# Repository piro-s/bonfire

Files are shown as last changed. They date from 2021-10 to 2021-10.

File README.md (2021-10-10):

# bonfire
Modernization of the night light bought on Ali in the form of a bonfire from Dark Souls.
The original uses three 5050 RGB LEDs with IR remote control. The range of this control is +- 50 centimeters, you can choose several glow colors. I created a new board to replace the one that was there, without control, just a glow in the form of a fluttering flame (it seems to work). The blue color of the diodes is not used, the red one works constantly, and green, with a PWM, turns out to be flickering yellow, creating the effect of a flame. Everything is controlled by one 48 mega, 6 PWM channels, each controls its own transistor, each has 8 LEDs.

Board size: circle, diameter 98 mm.
v0.1:
1. no remote control (why? It's a fire);
2. instead of 3 LEDs, now 48;
3. work from an external 5V source;
4. consumption about 350mA.

***
## scheme:
### scheme_v0.1:
[pdf](docs/scheme_v0.1.pdf)

***
## pcb:
#### top assambled:
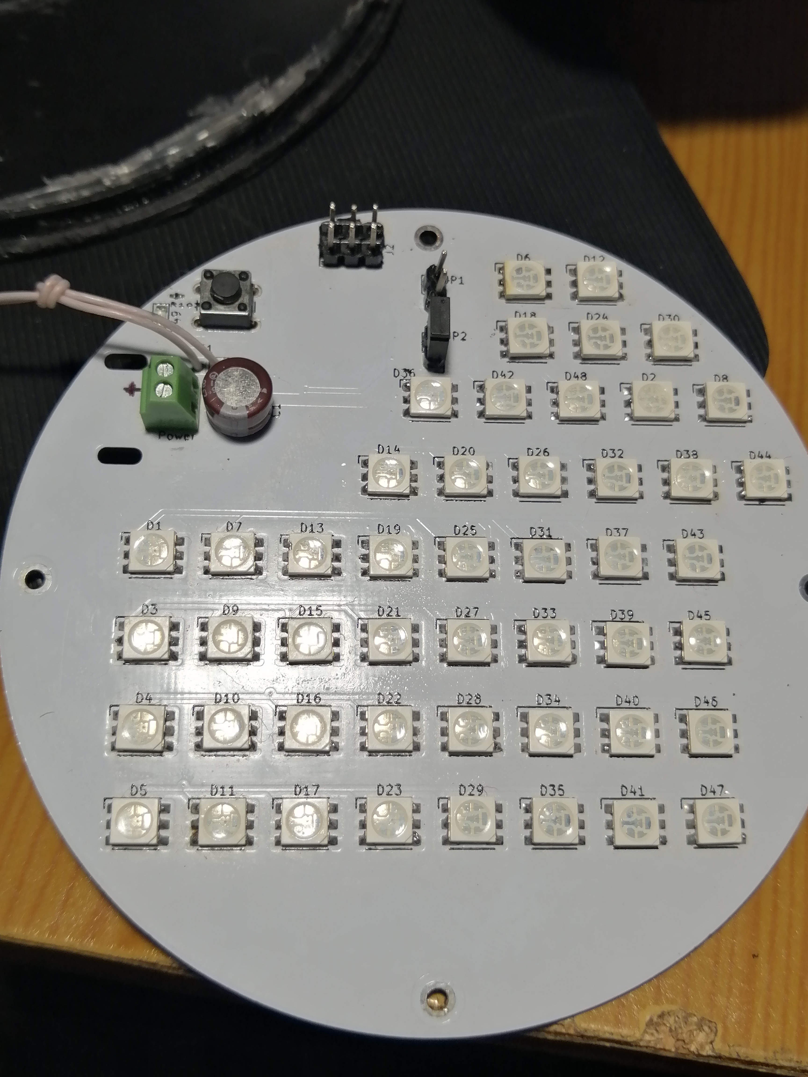
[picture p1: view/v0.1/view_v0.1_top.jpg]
top_assambled


***
## bonfire:
#### assambled:
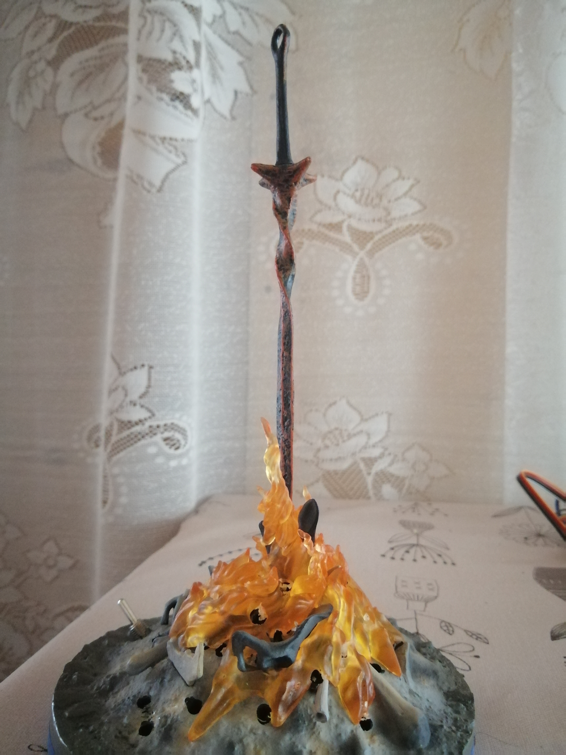
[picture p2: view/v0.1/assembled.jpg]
assambled

#### work:
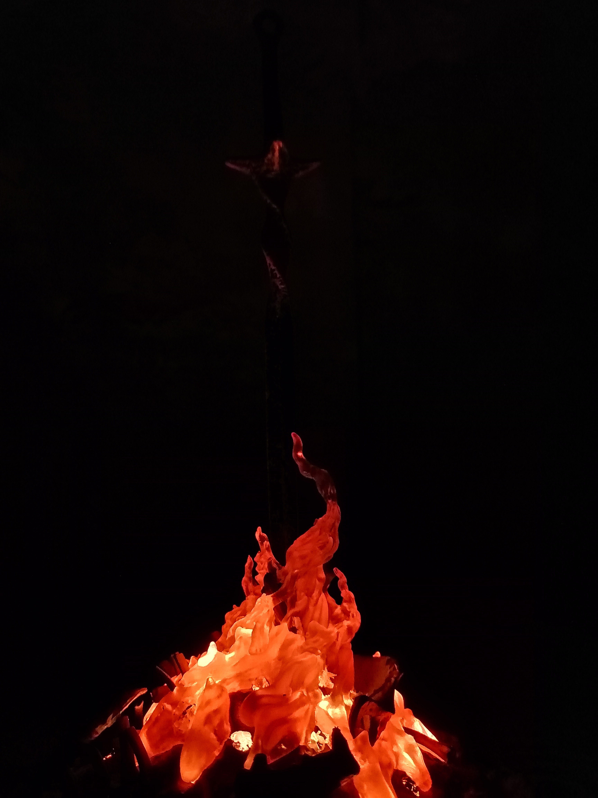
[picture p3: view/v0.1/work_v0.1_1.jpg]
work_1

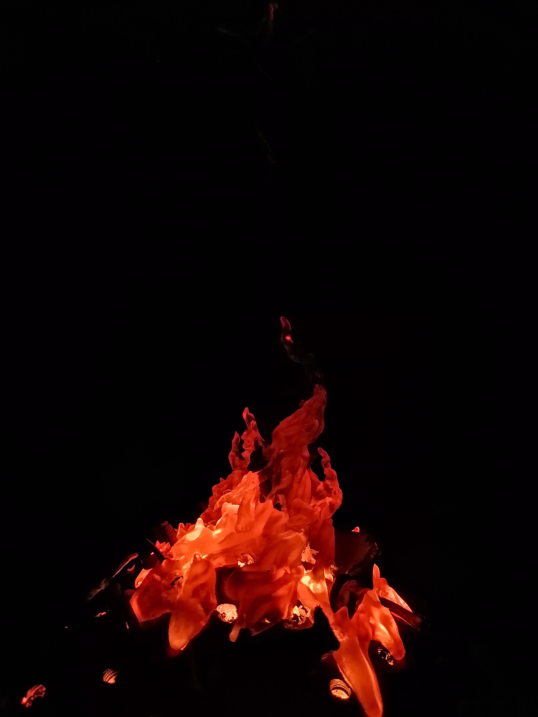
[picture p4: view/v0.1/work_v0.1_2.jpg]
work_2

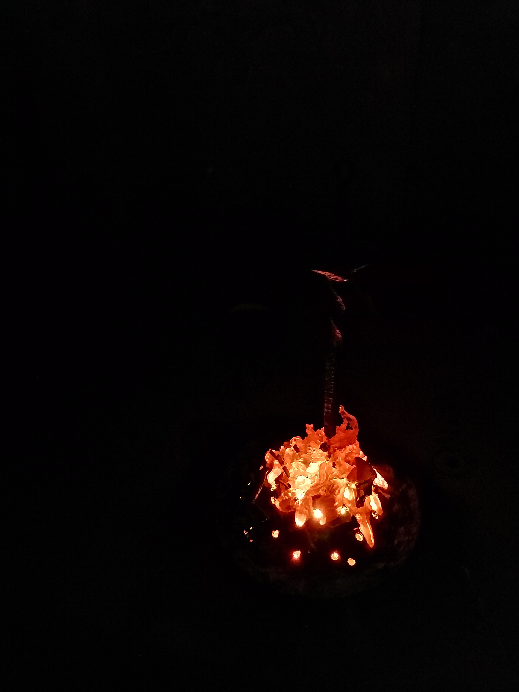
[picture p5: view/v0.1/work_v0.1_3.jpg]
work_3


***
## gerber:
Archive for production:
[gerber_v0.1](https://github.com/piro-s/bonfire/raw/master/gerber/bonfire_v0.1.zip)

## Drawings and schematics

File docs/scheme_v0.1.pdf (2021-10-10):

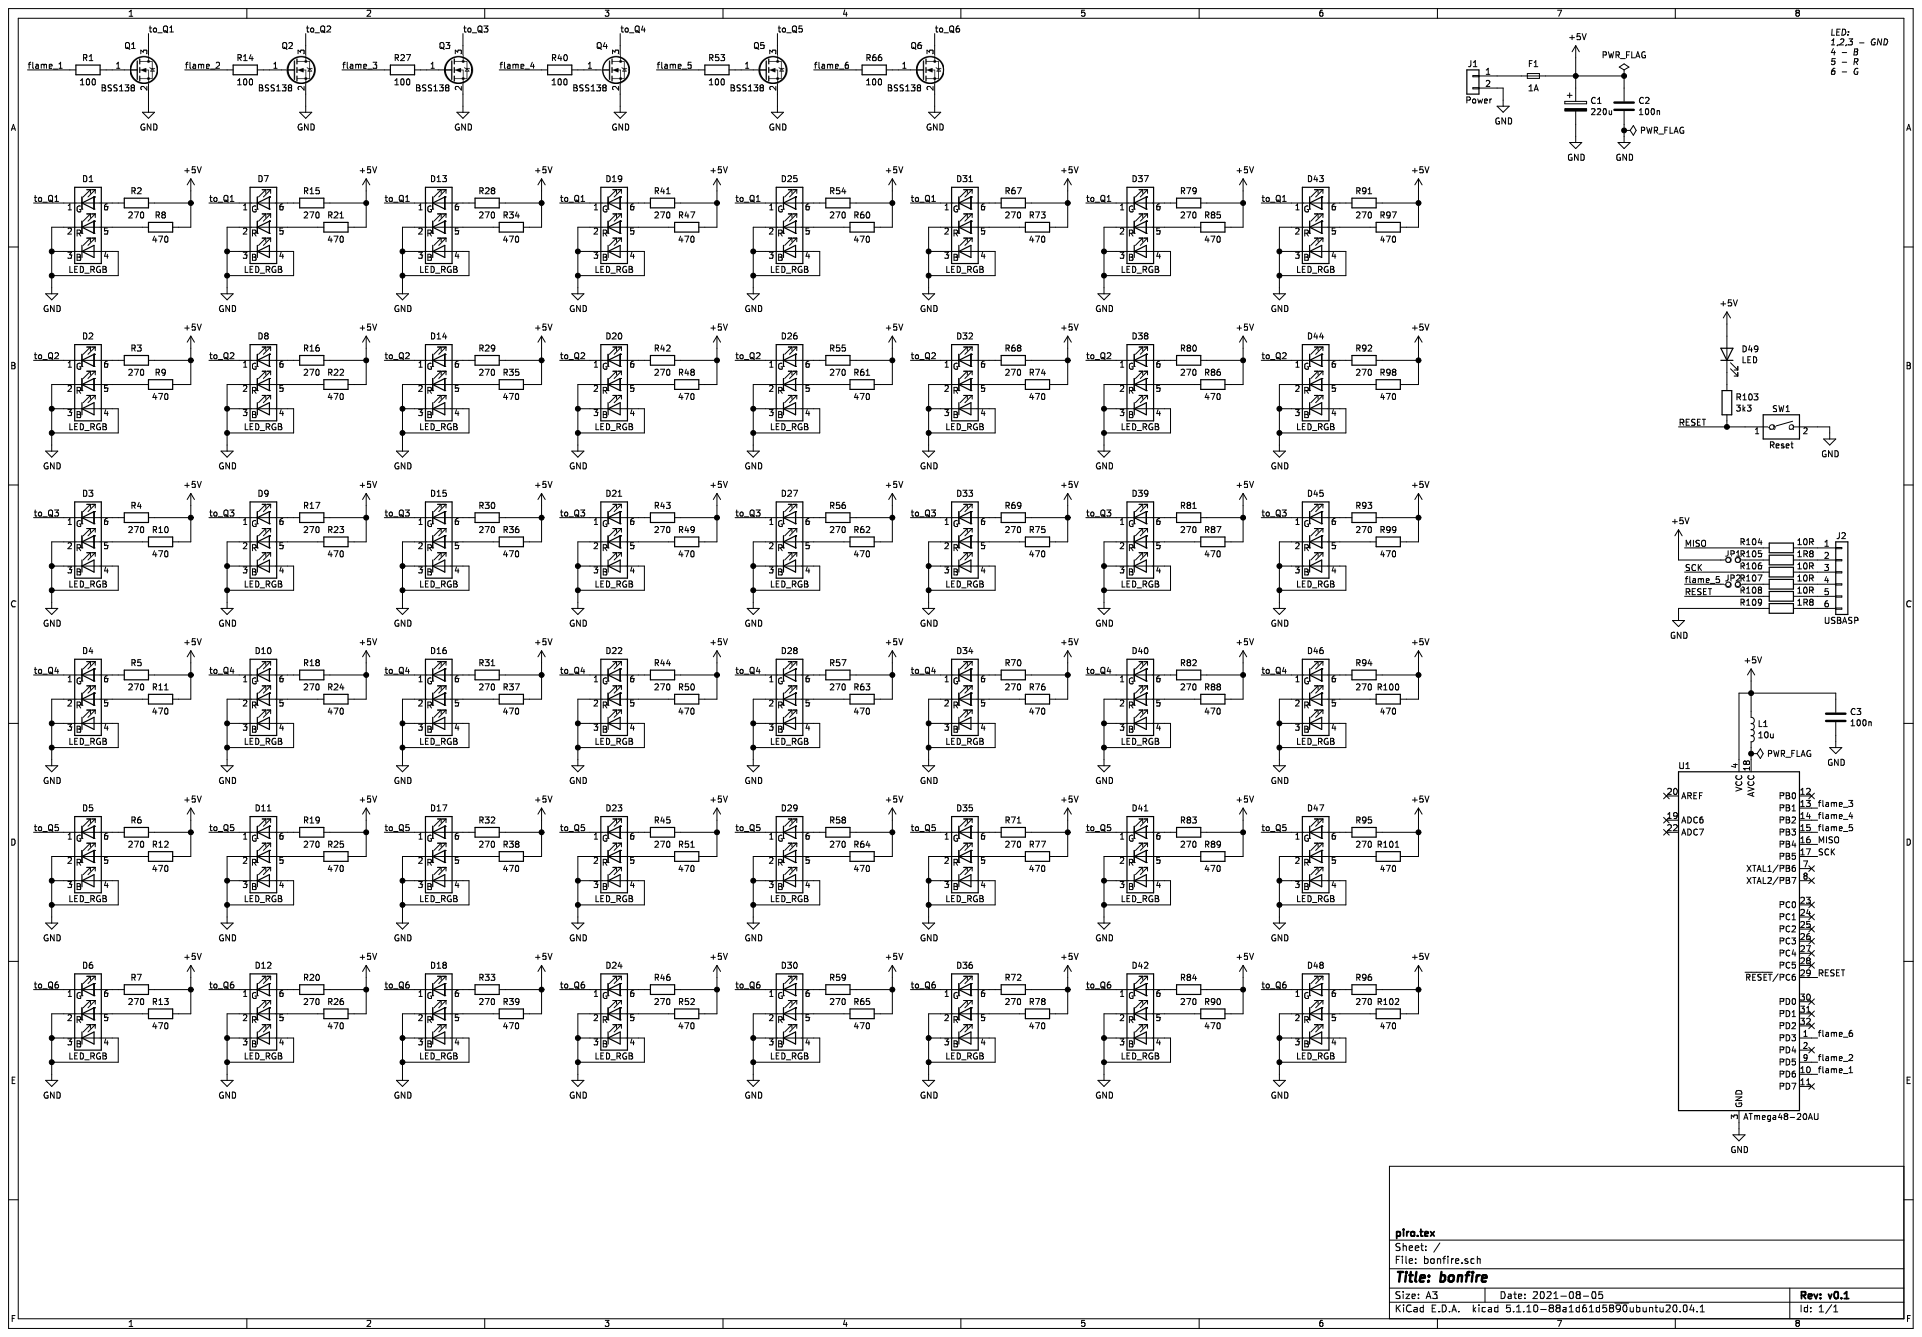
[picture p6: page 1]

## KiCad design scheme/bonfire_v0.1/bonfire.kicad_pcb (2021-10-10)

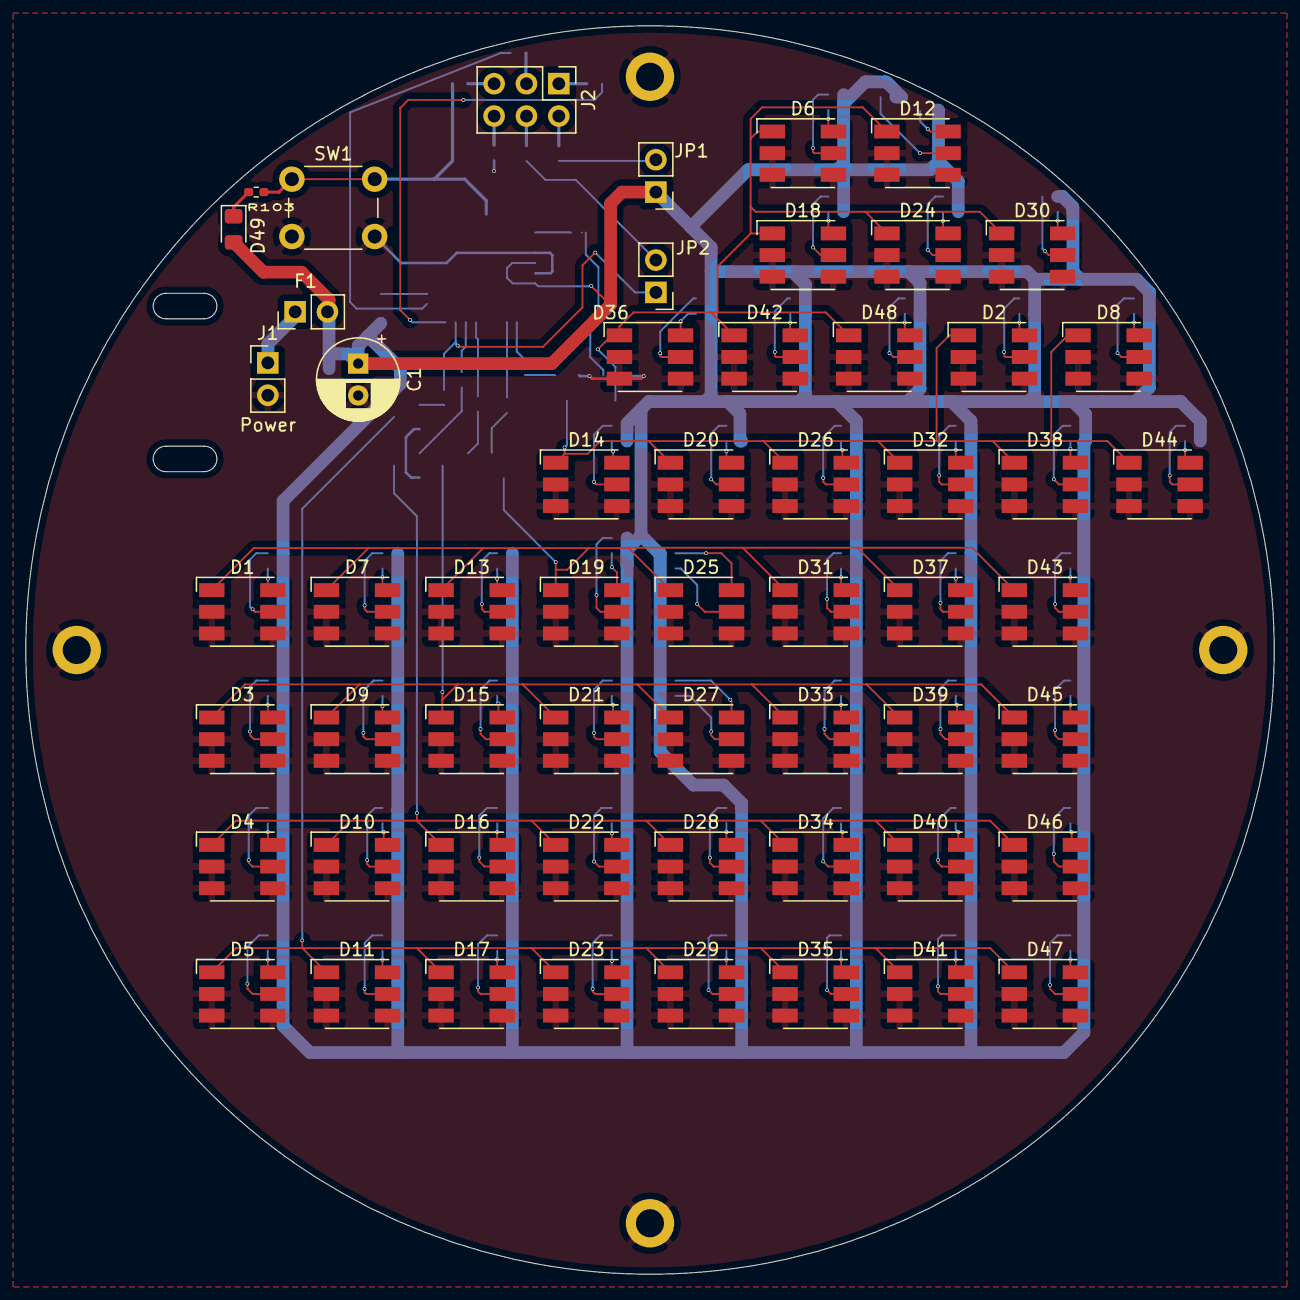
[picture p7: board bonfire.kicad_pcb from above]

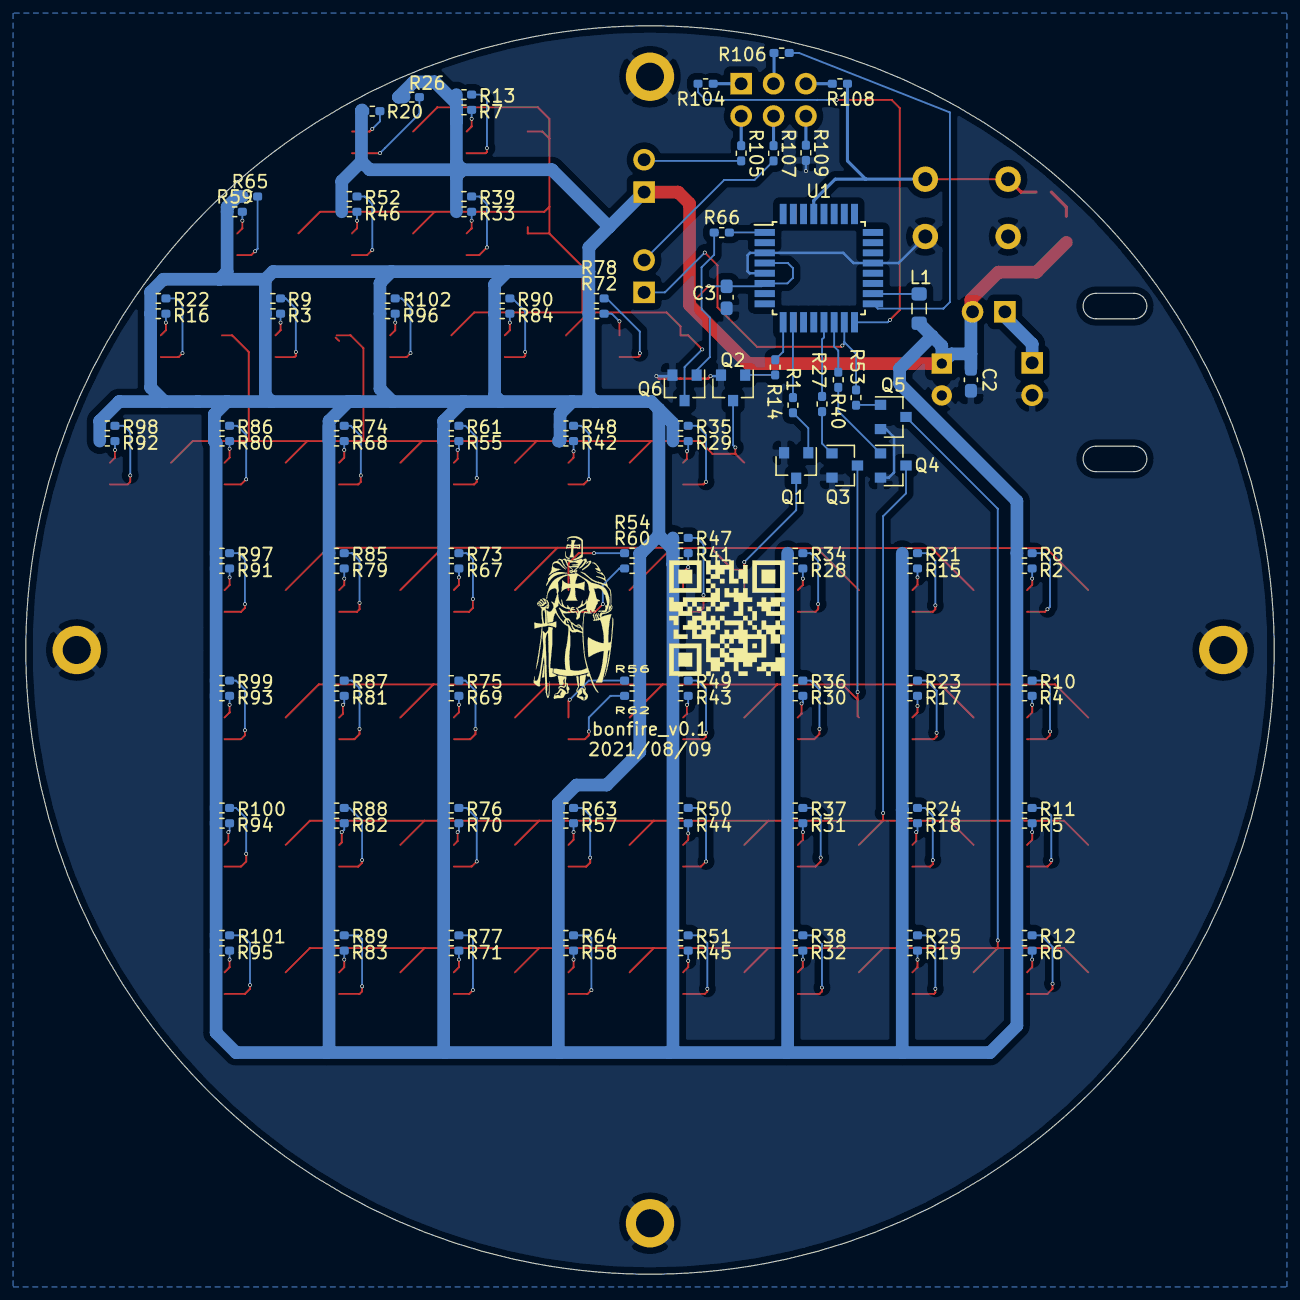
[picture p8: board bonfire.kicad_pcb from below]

Board: 2 copper layers, 98.0 x 98.0 mm, 175 parts (118 on the bottom side), 130 nets.

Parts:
C1: 220u; CP_Radial_D6.3mm_P2.50mm
C2, C3: 100n; C_0603_1608Metric_Pad1.08x0.95mm_HandSolder
D1, D2, D3, D4, D5, D6, D7, D8, D9, D10, D11, D12, D13, D14, D15, D16, D17, D18, D19, D20, D21, D22, D23, D24, D25, D26, D27, D28, D29, D30, D31, D32, D33, D34, D35, D36, D37, D38, D39, D40, D41, D42, D43, D44, D45, D46, D47, D48: LED_RGB; LED_RGB_5050-6
D49: LED; LED_0805_2012Metric_Pad1.15x1.40mm_HandSolder
F1: 1A; PinHeader_1x02_P2.54mm_Vertical
J1: Power; PinHeader_1x02_P2.54mm_Vertical
J2: USBASP; PinHeader_2x03_P2.54mm_Vertical
JP1, JP2: Jumper_NO_Small; PinHeader_1x02_P2.54mm_Vertical
L1: 10u; L_0805_2012Metric_Pad1.05x1.20mm_HandSolder
Q1, Q2, Q3, Q4, Q5, Q6: BSS138; SOT-23
R1, R14, R27, R40, R53, R66: 100; R_0402_1005Metric_Pad0.72x0.64mm_HandSolder
R2, R3, R4, R5, R6, R7, R15, R16, R17, R18, R19, R20, R28, R29, R30, R31, R32, R33, R41, R42, R43, R44, R45, R46, R54, R55, R56, R57, R58, R59, R67, R68, R69, R70, R71, R72, R79, R80, R81, R82, R83, R84, R91, R92, R93, R94, R95, R96: 270; R_0402_1005Metric_Pad0.72x0.64mm_HandSolder
R8, R9, R10, R11, R12, R13, R21, R22, R23, R24, R25, R26, R34, R35, R36, R37, R38, R39, R47, R48, R49, R50, R51, R52, R60, R61, R62, R63, R64, R65, R73, R74, R75, R76, R77, R78, R85, R86, R87, R88, R89, R90, R97, R98, R99, R100, R101, R102: 470; R_0402_1005Metric_Pad0.72x0.64mm_HandSolder
R103: 3k3; R_0402_1005Metric_Pad0.72x0.64mm_HandSolder
R104, R106, R107, R108: 10R; R_0402_1005Metric_Pad0.72x0.64mm_HandSolder
R105, R109: 1R8; R_0402_1005Metric_Pad0.72x0.64mm_HandSolder
SW1: Reset; SW_PUSH_6mm
U1: ATmega48-20AU; TQFP-32_7x7mm_P0.8mm

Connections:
+5V: C1.1, C2.1, C3.1, D49.2, F1.2, JP1.1, L1.1, R2.1, R3.1, R4.1, R5.1, R6.1, R7.1, R8.1, R9.1, R10.1, R11.1, R12.1, R13.1, R15.1, R16.1, R17.1, R18.1, R19.1, R20.1, R21.1, R22.1, R23.1, R24.1, R25.1, R26.1, R28.1, R29.1, R30.1, R31.1, R32.1, R33.1, R34.1, R35.1, R36.1, R37.1, R38.1, R39.1, R41.1, R42.1, R43.1, R44.1, R45.1, R46.1, R47.1, R48.1, R49.1, R50.1, R51.1, R52.1, R54.1, R55.1, R56.1, R57.1, R58.1, R59.1, R60.1, R61.1, R62.1, R63.1, R64.1, R65.1, R67.1, R68.1, R69.1, R70.1, R71.1, R72.1, R73.1, R74.1, R75.1, R76.1, R77.1, R78.1, R79.1, R80.1, R81.1, R82.1, R83.1, R84.1, R85.1, R86.1, R87.1, R88.1, R89.1, R90.1, R91.1, R92.1, R93.1, R94.1, R95.1, R96.1, R97.1, R98.1, R99.1, R100.1, R101.1, R102.1, U1.4, U1.6
/MISO: R104.2, U1.16
/RESET: R103.2, R108.2, SW1.1, U1.29
/SCK: R106.2, U1.17
/flame_1: R1.2, U1.10
/flame_2: R14.2, U1.9
/flame_3: R27.2, U1.13
/flame_4: R40.2, U1.14
/flame_5: JP2.1, R53.2, U1.15
/flame_6: R66.2, U1.1
/to_Q1: D1.1, D7.1, D13.1, D19.1, D25.1, D31.1, D37.1, D43.1, Q1.3
/to_Q2: D2.1, D8.1, D14.1, D20.1, D26.1, D32.1, D38.1, D44.1, Q2.3
/to_Q3: D3.1, D9.1, D15.1, D21.1, D27.1, D33.1, D39.1, D45.1, Q3.3
/to_Q4: D4.1, D10.1, D16.1, D22.1, D28.1, D34.1, D40.1, D46.1, Q4.3
/to_Q5: D5.1, D11.1, D17.1, D23.1, D29.1, D35.1, D41.1, D47.1, Q5.3
/to_Q6: D6.1, D12.1, D18.1, D24.1, D30.1, D36.1, D42.1, D48.1, Q6.3
GND: C1.2, C2.2, C3.2, D1.2, D1.3, D1.4, D2.2, D2.3, D2.4, D3.2, D3.3, D3.4, D4.2, D4.3, D4.4, D5.2, D5.3, D5.4, D6.2, D6.3, D6.4, D7.2, D7.3, D7.4, D8.2, D8.3, D8.4, D9.2, D9.3, D9.4, D10.2, D10.3, D10.4, D11.2, D11.3, D11.4, D12.2, D12.3, D12.4, D13.2, D13.3, D13.4, D14.2, D14.3, D14.4, D15.2, D15.3, D15.4, D16.2, D16.3, D16.4, D17.2, D17.3, D17.4, D18.2, D18.3, D18.4, D19.2, D19.3, D19.4, D20.2, D20.3, D20.4, D21.2, D21.3, D21.4, D22.2, D22.3, D22.4, D23.2, D23.3, D23.4, D24.2, D24.3, D24.4, D25.2, D25.3, D25.4, D26.2, D26.3, D26.4, D27.2, D27.3, D27.4, D28.2, D28.3, D28.4, D29.2, D29.3, D29.4, D30.2, D30.3, D30.4, D31.2, D31.3, D31.4, D32.2, D32.3, D32.4, D33.2, D33.3, D33.4, D34.2, D34.3, D34.4, D35.2, D35.3, D35.4, D36.2, D36.3, D36.4, D37.2, D37.3, D37.4, D38.2, D38.3, D38.4, D39.2, D39.3, D39.4, D40.2, D40.3, D40.4, D41.2, D41.3, D41.4, D42.2, D42.3, D42.4, D43.2, D43.3, D43.4, D44.2, D44.3, D44.4, D45.2, D45.3, D45.4, D46.2, D46.3, D46.4, D47.2, D47.3, D47.4, D48.2, D48.3, D48.4, J1.2, Q1.2, Q2.2, Q3.2, Q4.2, Q5.2, Q6.2, R109.2, SW1.2, U1.3, U1.5, U1.21
unnamed: D1.5, R8.2
unnamed: D1.6, R2.2
unnamed: D2.5, R9.2
unnamed: D2.6, R3.2
unnamed: D3.5, R10.2
unnamed: D3.6, R4.2
unnamed: D4.5, R11.2
unnamed: D4.6, R5.2
unnamed: D5.5, R12.2
unnamed: D5.6, R6.2
unnamed: D6.5, R13.2
unnamed: D6.6, R7.2
unnamed: D7.5, R21.2
unnamed: D7.6, R15.2
unnamed: D8.5, R22.2
unnamed: D8.6, R16.2
unnamed: D9.5, R23.2
unnamed: D9.6, R17.2
unnamed: D10.5, R24.2
unnamed: D10.6, R18.2
unnamed: D11.5, R25.2
unnamed: D11.6, R19.2
unnamed: D12.5, R26.2
unnamed: D12.6, R20.2
unnamed: D13.5, R34.2
unnamed: D13.6, R28.2
unnamed: D14.5, R35.2
unnamed: D14.6, R29.2
unnamed: D15.5, R36.2
unnamed: D15.6, R30.2
unnamed: D16.5, R37.2
unnamed: D16.6, R31.2
unnamed: D17.5, R38.2
unnamed: D17.6, R32.2
unnamed: D18.5, R39.2
unnamed: D18.6, R33.2
unnamed: D19.5, R47.2
unnamed: D19.6, R41.2
unnamed: D20.5, R48.2
unnamed: D20.6, R42.2
unnamed: D21.5, R49.2
unnamed: D21.6, R43.2
unnamed: D22.5, R50.2
unnamed: D22.6, R44.2
unnamed: D23.5, R51.2
unnamed: D23.6, R45.2
unnamed: D24.5, R52.2
unnamed: D24.6, R46.2
unnamed: D25.5, R60.2
unnamed: D25.6, R54.2
unnamed: D26.5, R61.2
unnamed: D26.6, R55.2
unnamed: D27.5, R62.2
unnamed: D27.6, R56.2
unnamed: D28.5, R63.2
unnamed: D28.6, R57.2
unnamed: D29.5, R64.2
unnamed: D29.6, R58.2
unnamed: D30.5, R65.2
unnamed: D30.6, R59.2
unnamed: D31.5, R73.2
unnamed: D31.6, R67.2
unnamed: D32.5, R74.2
unnamed: D32.6, R68.2
unnamed: D33.5, R75.2
unnamed: D33.6, R69.2
unnamed: D34.5, R76.2
unnamed: D34.6, R70.2
unnamed: D35.5, R77.2
unnamed: D35.6, R71.2
unnamed: D36.5, R78.2
unnamed: D36.6, R72.2
unnamed: D37.5, R85.2
unnamed: D37.6, R79.2
unnamed: D38.5, R86.2
unnamed: D38.6, R80.2
unnamed: D39.5, R87.2
unnamed: D39.6, R81.2
unnamed: D40.5, R88.2
unnamed: D40.6, R82.2
unnamed: D41.5, R89.2
unnamed: D41.6, R83.2
unnamed: D42.5, R90.2
unnamed: D42.6, R84.2
unnamed: D43.5, R97.2
unnamed: D43.6, R91.2
unnamed: D44.5, R98.2
unnamed: D44.6, R92.2
unnamed: D45.5, R99.2
unnamed: D45.6, R93.2
unnamed: D46.5, R100.2
unnamed: D46.6, R94.2
unnamed: D47.5, R101.2
unnamed: D47.6, R95.2
unnamed: D48.5, R102.2
unnamed: D48.6, R96.2
unnamed: D49.1, R103.1
unnamed: F1.1, J1.1
unnamed: J2.1, R104.1
unnamed: J2.2, R105.1
unnamed: J2.3, R106.1
unnamed: J2.4, R107.1
unnamed: J2.5, R108.1
unnamed: J2.6, R109.1
unnamed: JP1.2, R105.2
unnamed: JP2.2, R107.2
unnamed: L1.2, U1.18
unnamed: Q1.1, R1.1
unnamed: Q2.1, R14.1
unnamed: Q3.1, R27.1
unnamed: Q4.1, R40.1
unnamed: Q5.1, R53.1
unnamed: Q6.1, R66.1

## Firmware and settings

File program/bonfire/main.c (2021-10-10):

/*
 * bonfire.c
 *
 * Created: 27.07.2021 9:35:37
 * Author : piro.tex
 */ 


///--- defines
#define F_CPU 1000000UL

#define flame_1 OCR0A
#define flame_2 OCR0B
#define flame_3 OCR1A
#define flame_4 OCR1B
#define flame_5 OCR2A
#define flame_6 OCR2B


///--- includes
#include <avr/io.h>
#include <util/delay.h>


///--- enums
enum flames
{
    // PWM pins
    flame_1_pin     = 6,
    flame_2_pin     = 5,
    flame_3_pin     = 1,
    flame_4_pin     = 2,
    flame_5_pin     = 3,
    flame_6_pin     = 3,
    
    // flames in mass
    flame_1_pos     = 0,
    flame_2_pos     = 1,
    flame_3_pos     = 2,
    flame_4_pos     = 3,
    flame_5_pos     = 4,
    flame_6_pos     = 5,
};


///--- init
void init_PWM(void);
void init_LED(void);


///--- functionts
void flame_pwm(uint8_t flame); // kindle a fire


///--- consts
//const uint8_t flame_max[6] = { 35, 30, 25, 20, 15, 10 };
const uint8_t flame_max[6] = { 50, 40, 30, 20, 10, 8 };


///--- variables
uint8_t flame_val[6] = { 0x00, 0x00, 0x00, 0x00, 0x00, 0x00 }; // pwm value


///-----------------------------------------------------------------------------
int main(void)
{
    init_PWM();
    init_LED();
    
    uint8_t timer = 0;
    
    while(1)
    {       
        if(timer % 25 == 0)
            flame_pwm(flame_6_pos);
        if(timer % 20 == 0)
            flame_pwm(flame_5_pos);
        if(timer % 17 == 0)
            flame_pwm(flame_4_pos);
        if(timer % 9 == 0)
            flame_pwm(flame_3_pos);
        if(timer % 4 == 0)
            flame_pwm(flame_2_pos);
        if(timer % 20 == 0)
            flame_pwm(flame_1_pos);
        
        
        timer++;
        _delay_ms(1);
    } // while (1)
} // int main(void)
///-----------------------------------------------------------------------------


///--- init
void init_PWM(void)
{
    ///--- TIM0 - fast pwm
    TCCR0A = ((1 << COM0A1) | (1 << COM0B1) | (1 << WGM00) | (1 << WGM01));
    TCCR0B |= (1 << CS10);
    TCNT0 = 0x00;
    OCR0A = 0x00;
    OCR0B = 0x00;
    TIMSK0 |= 0x00;
    
    ///--- TIM1 - fast pwm
    TCCR1A = ((1 << COM1A1) | (1 << COM1B1) | (1 << WGM10) | (1 << WGM12));
    TCCR1B |= (1 << CS10);
    TCNT1 = 0x00;
    OCR1A = 0x00;
    OCR1B = 0x00;
    TIMSK1 |= 0x00;
    
    ///--- TIM2 - fast pwm
    TCCR2A = ((1 << COM2A1) | (1 << COM2B1) | (1 << WGM20) | (1 << WGM21));
    TCCR2B |= (1 << CS10);
    TCNT2 = 0x00;
    OCR2A = 0x00;
    OCR2B = 0x00;
    TIMSK2 |= 0x00;
    
    return;
} // void init_PWM(void)

void init_LED(void)
{
    // Ports as out
    DDRD |= ((1 << flame_1_pin) | (1 << flame_2_pin) | (1 << flame_6_pin));
    DDRB |= ((1 << flame_3_pin) | (1 << flame_4_pin) | (1 << flame_5_pin));
    
    // Init ports value
    PORTD &= ~((1 << flame_1_pin) | (1 << flame_2_pin) | (1 << flame_6_pin));
    PORTB &= ~((1 << flame_3_pin) | (1 << flame_4_pin) | (1 << flame_5_pin));
    
    return;
} // void init_LED(void)


///-----------------------------------------------------------------------------
///--- functionts
void flame_pwm(uint8_t flame) // kindle a fire
{
    flame_val[flame]++; // set next pwm value
    if(flame_val[flame] >= flame_max[flame]) // if max pwm
        flame_val[flame] = 0; // set pwm 0
        
    switch(flame)
    {
        case flame_1_pos:
            flame_1 = flame_val[flame]; // set pwm
            break;
        case flame_2_pos:
            flame_2 = flame_val[flame]; // set pwm
            break;
        case flame_3_pos:
            flame_3 = flame_val[flame]; // set pwm
            break;
        case flame_4_pos:
            flame_4 = flame_val[flame]; // set pwm
            break;
        case flame_5_pos:
            flame_5 = flame_val[flame]; // set pwm
            break;
        case flame_6_pos:
            flame_6 = flame_val[flame]; // set pwm
            break;
    } // switch(flame)
    
    return;
} // flame_pwm
